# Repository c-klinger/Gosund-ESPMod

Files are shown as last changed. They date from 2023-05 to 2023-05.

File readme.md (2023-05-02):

# Gosund-ESPMod
Adapter PCB to replace the CUCO-Z0 Modules on newer Gosund Smart Plugs with ESP-M2 Modules. Enables to use custom firmware like [Tasmota](https://tasmota.github.io/docs/) again.

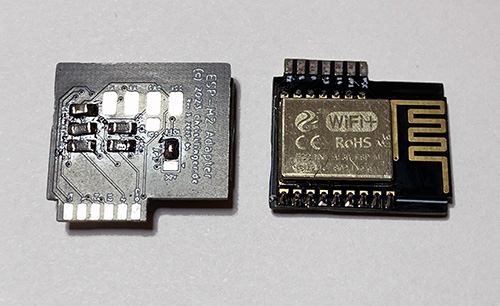
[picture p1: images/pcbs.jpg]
PCB Picture


[Schematics](https://github.com/c-klinger/Gosund-ESPMod/blob/main/gosund-esp-adapter.pdf)

The PCB features a Solder Jumper on the back side to control the pin mapping. 

## Tested Devices

### Gosund SP112, SP112_MAIN_AI_V1.0.
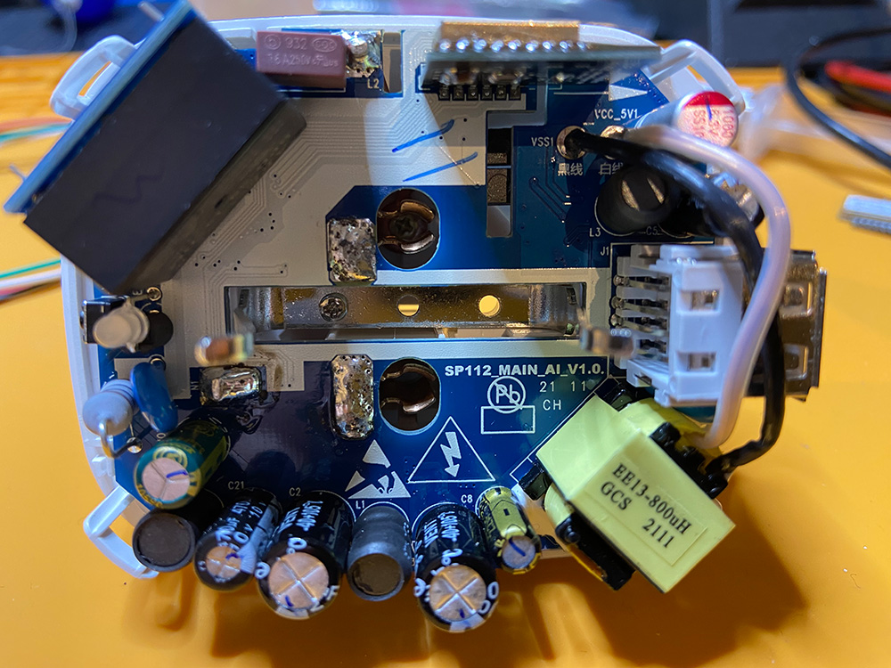
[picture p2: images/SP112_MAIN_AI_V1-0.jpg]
SP112_MAIN_AI_V1.0


**PCB:** IO16 and JP1 have to be shorted.

**Tasmota Template:** ``{"NAME":"Gosund SP112 ESP-M2","GPIO":[288,0,289,0,2656,2720,0,0,2624,257,224,0,32,0],"FLAG":0,"BASE":18}``

## PCB Specification
- Dimension: 20.3 mm * 18.7 mm
- PCB Thickness: 0.8mm

## Bill of Material

| Pos | References | Description | Value | Size | Quantity | Order Links \* | Notes |
|-----|---|---|---|---|---|---|---|
| 01 | U1 | ESP8285:ESP-M2 |  | ESP-M2 | 1 | [Aliexpress](https://s.click.aliexpress.com/e/_DFF7SI1) | |
| 02 | C1 | Capacitor | 100nF | 0805 | 1 | [Aliexpress](https://s.click.aliexpress.com/e/_DCEFDlb) | |
| 03 | R1, R2, R3, R4 | Resistor | 10k | 0805 | 4 | [Aliexpress](https://s.click.aliexpress.com/e/_DFfLtiN)  | 

\* *I have not tested all parts using this order links, no guarantee that every linked component works. Aliexpress links are affiliate links, so i will get a small commission when you order using this link. This will help me with further projects. Thanks.*

## LICENSE


All content in this repository is is licensed under a [Creative Commons Attribution-NonCommercial-ShareAlike 4.0 International license](https://creativecommons.org/licenses/by-nc-sa/4.0/).

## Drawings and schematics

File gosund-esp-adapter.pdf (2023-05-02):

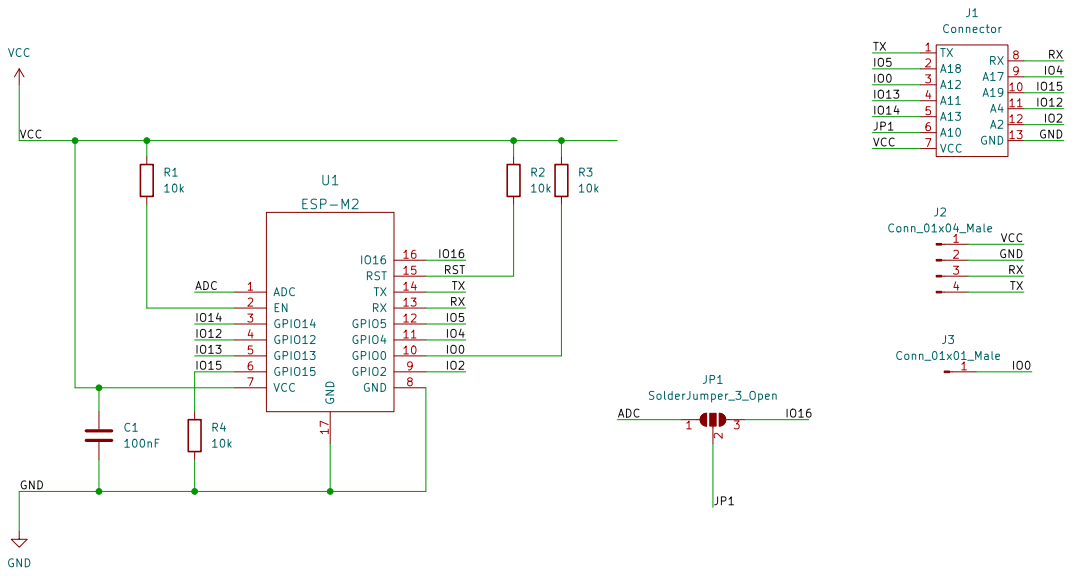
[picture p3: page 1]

File: gosund-esp-adapter.kicad_sch Sheet: / chrisklinger.de

Id: 1/1 Title: Gosund-ESPMod

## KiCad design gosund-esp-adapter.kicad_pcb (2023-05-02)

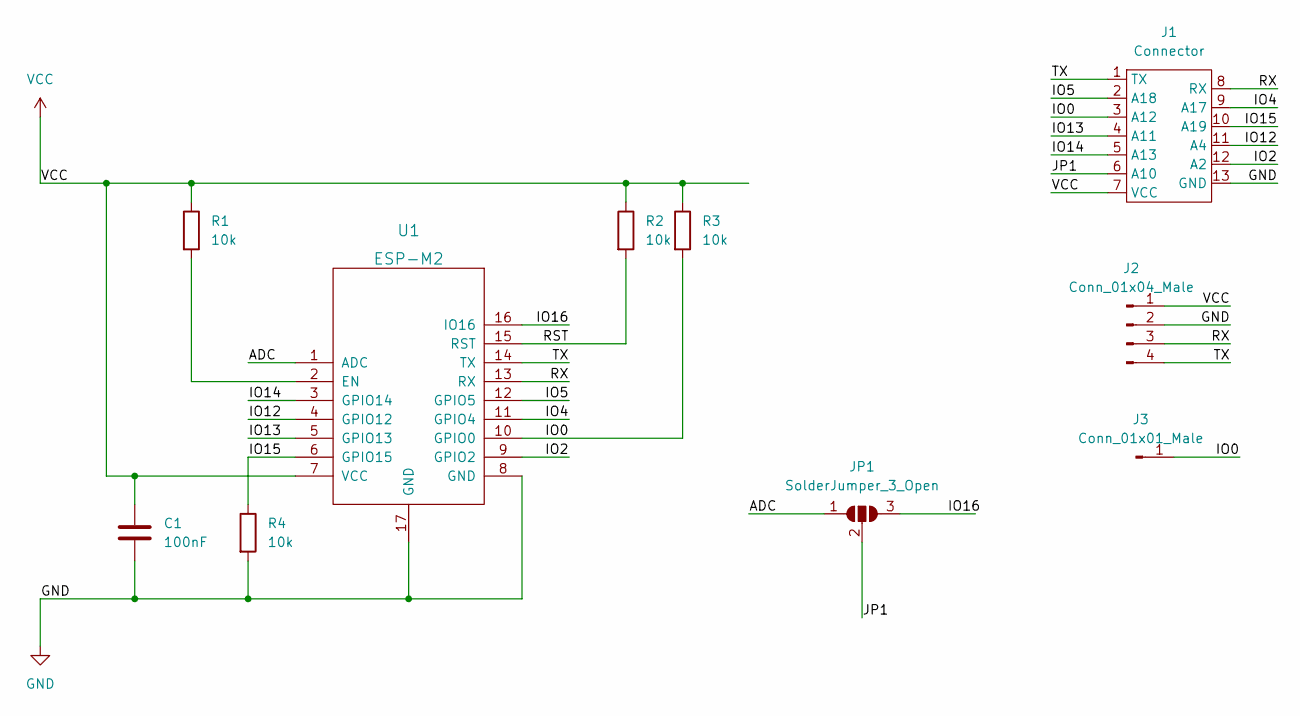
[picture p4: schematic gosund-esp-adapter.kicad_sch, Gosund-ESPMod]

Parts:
C1: 100nF; C_0805_2012Metric_Pad1.18x1.45mm_HandSolder
J1: Connector; PCBConnector
J2: Conn_01x04_Male; FDTI
J3: Conn_01x01_Male; IO0
JP1: SolderJumper_3_Open; SolderJumper-3_P1.3mm_Open_Pad1.0x1.5mm
R1, R2, R3, R4: 10k; R_0805_2012Metric_Pad1.20x1.40mm_HandSolder
U1: ESP-M2

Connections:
/ADC: JP1.1 (A), U1.1 (ADC)
/IO0: J1.3 (A12), J3.1, R3.2, U1.10 (GPIO0)
/IO2: J1.12 (A2), U1.9 (GPIO2)
/IO4: J1.9 (A17), U1.11 (GPIO4)
/IO5: J1.2 (A18), U1.12 (GPIO5)
/IO12: J1.11 (A4), U1.4 (GPIO12)
/IO13: J1.4 (A11), U1.5 (GPIO13)
/IO14: J1.5 (A13), U1.3 (GPIO14)
/IO15: J1.10 (A19), R4.1, U1.6 (GPIO15)
/IO16: JP1.3 (B), U1.16 (IO16)
/JP1: J1.6 (A10), JP1.2 (C)
/RST: R2.2, U1.15 (RST)
/RX: J1.8 (RX), J2.3, U1.13 (RX)
/TX: J1.1 (TX), J2.4, U1.14 (TX)
GND: C1.2, J1.13 (GND), J2.2, R4.2, U1.8 (GND), U1.17 (GND)
unnamed: R1.2, U1.2 (EN)
VCC: C1.1, J1.7 (VCC), J2.1, R1.1, R2.1, R3.1, U1.7 (VCC)

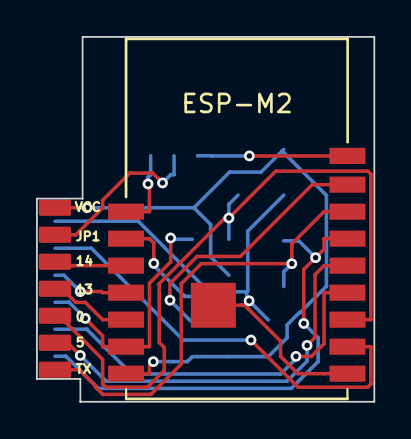
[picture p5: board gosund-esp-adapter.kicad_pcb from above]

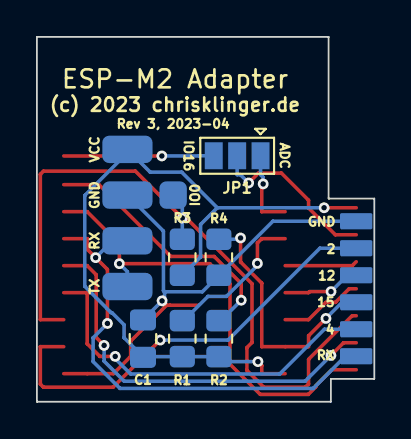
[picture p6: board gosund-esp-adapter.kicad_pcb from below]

Board: 2 copper layers, 18.7 x 20.3 mm, 10 parts (8 on the bottom side), 17 nets.

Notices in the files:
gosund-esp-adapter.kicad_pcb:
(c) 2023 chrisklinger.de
